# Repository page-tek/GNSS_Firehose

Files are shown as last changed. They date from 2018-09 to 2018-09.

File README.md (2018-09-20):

# GNSS Firehose

Design files for a triband wideband GNSS front-end board.  The board can digitizes three 50 MHz RF channels, emits 2-bit IQ samples to gigabit Ethernet (~800 Mbit/s total payload).

Includes schematics and PCB layout for the hardware design, HDL and software for the FPGA.

The board can by used with Peter Monta's python code (https://github.com/pmonta/GNSS-DSP-tools) or with SDRs like GNSS-SDR (https://gnss-sdr.org/).

See the Github Wiki for more detail on how to use the board.

Open-source licensing.

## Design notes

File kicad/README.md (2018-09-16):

# GNSS Firehose PCB

Created using Kicad 5, there could be issue if the design is opened in Kicad 4.

Changes made from Peter Monta's GNSS Firehose version 2.2 (April 2017) design:
- FPGA changed to Spartan6 XC6SLX16 BGA256 device, the fooprint should be compatable with larger gate devices.
- Power supply topology changes to allow the analog and digital 3V3 sections to be run off different regulators.
- Added the ability to running the frequency generation from external clock source
- Changed obsolite Broadcom MGA-68563 to BGA2800

Layout changes:
- Ground planes cover the outside PCB layers
- Slot in ground plane between TCXO and ethernet components
- more direct traces between the FPGA, Ethernet IC and Ethernet connector

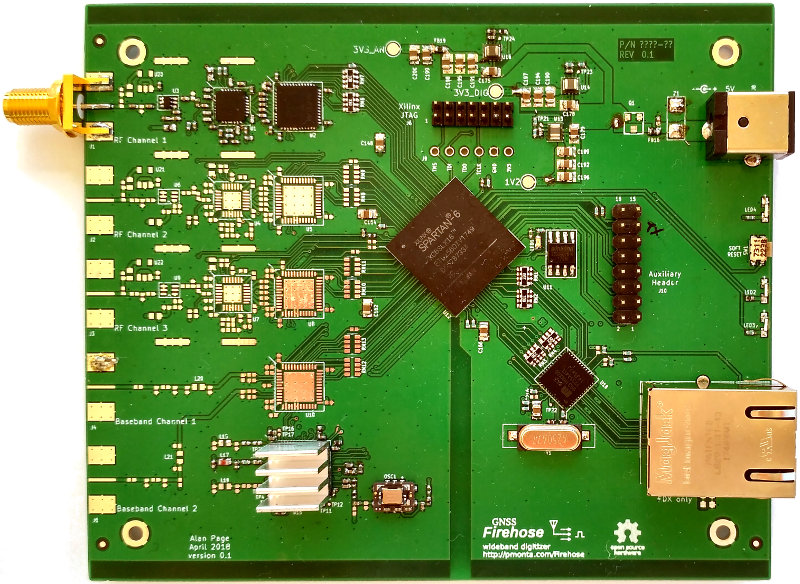
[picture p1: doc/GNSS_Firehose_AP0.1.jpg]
GNSS Firehose Image


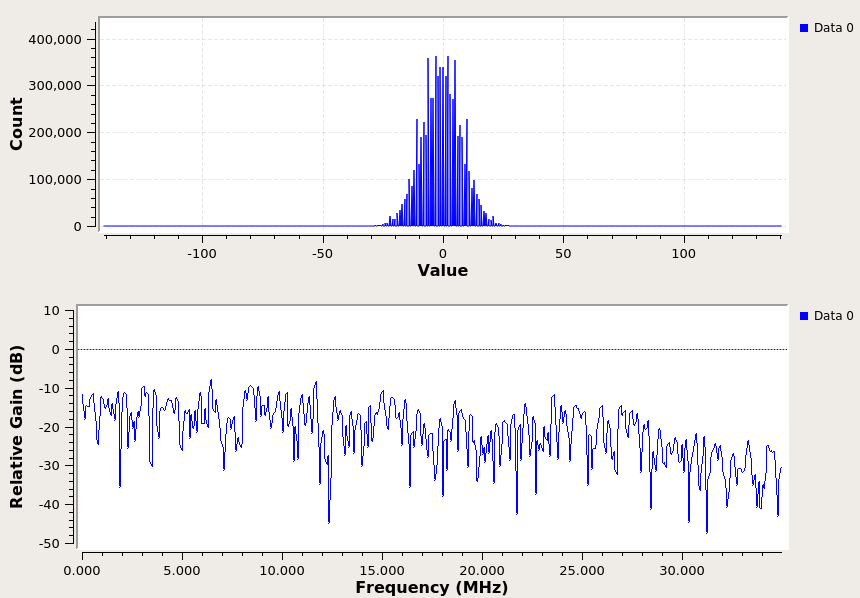
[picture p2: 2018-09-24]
doc/histogram/hist.png

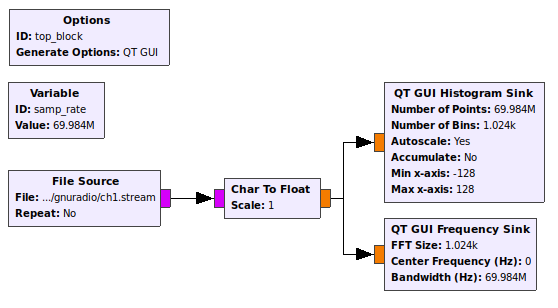
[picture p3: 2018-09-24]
doc/histogram/ch1_stream.png

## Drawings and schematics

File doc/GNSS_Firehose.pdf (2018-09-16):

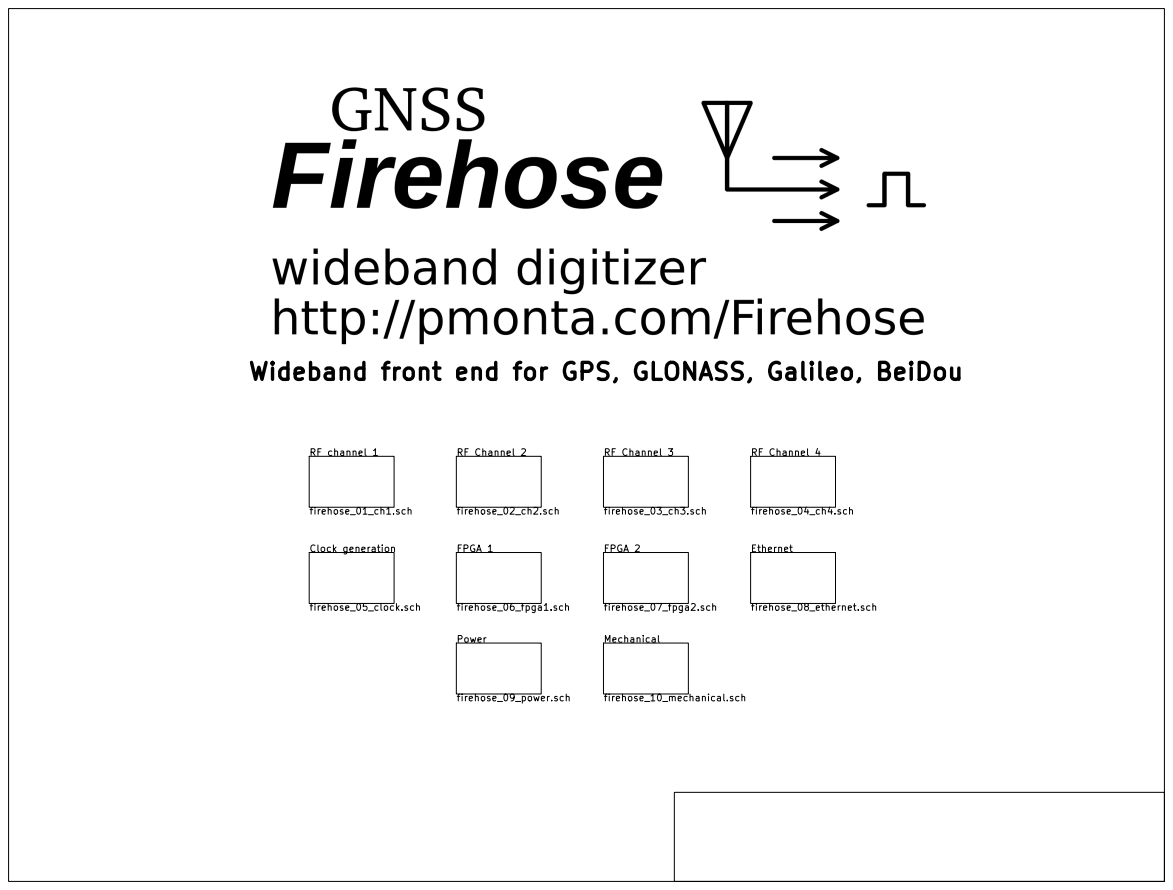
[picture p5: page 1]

Wideband front end for GPS, GLONASS, Galileo, BeiDou

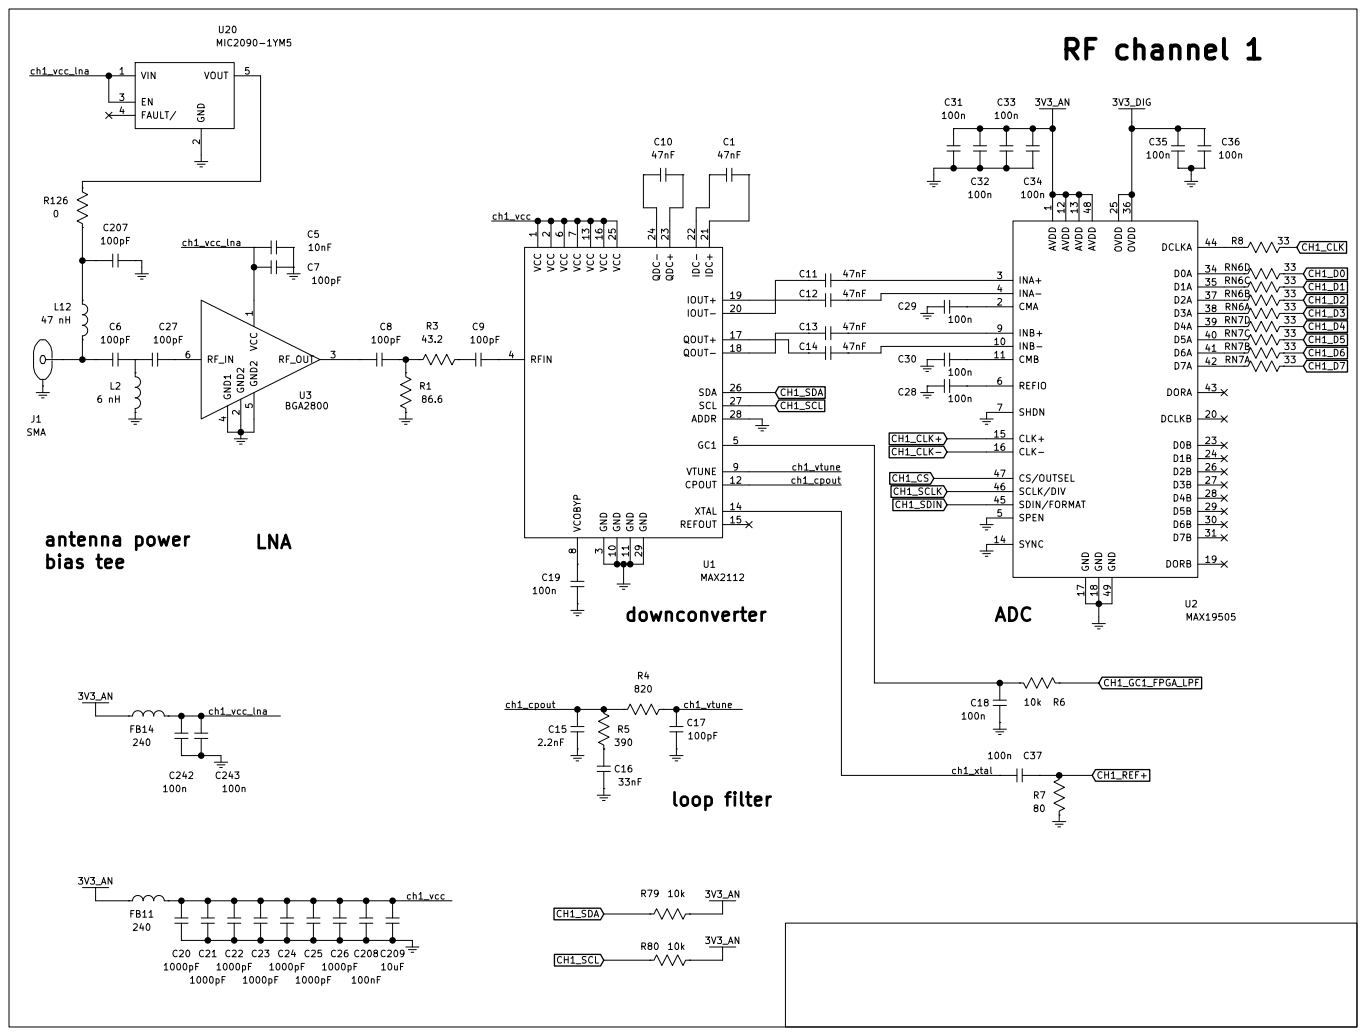
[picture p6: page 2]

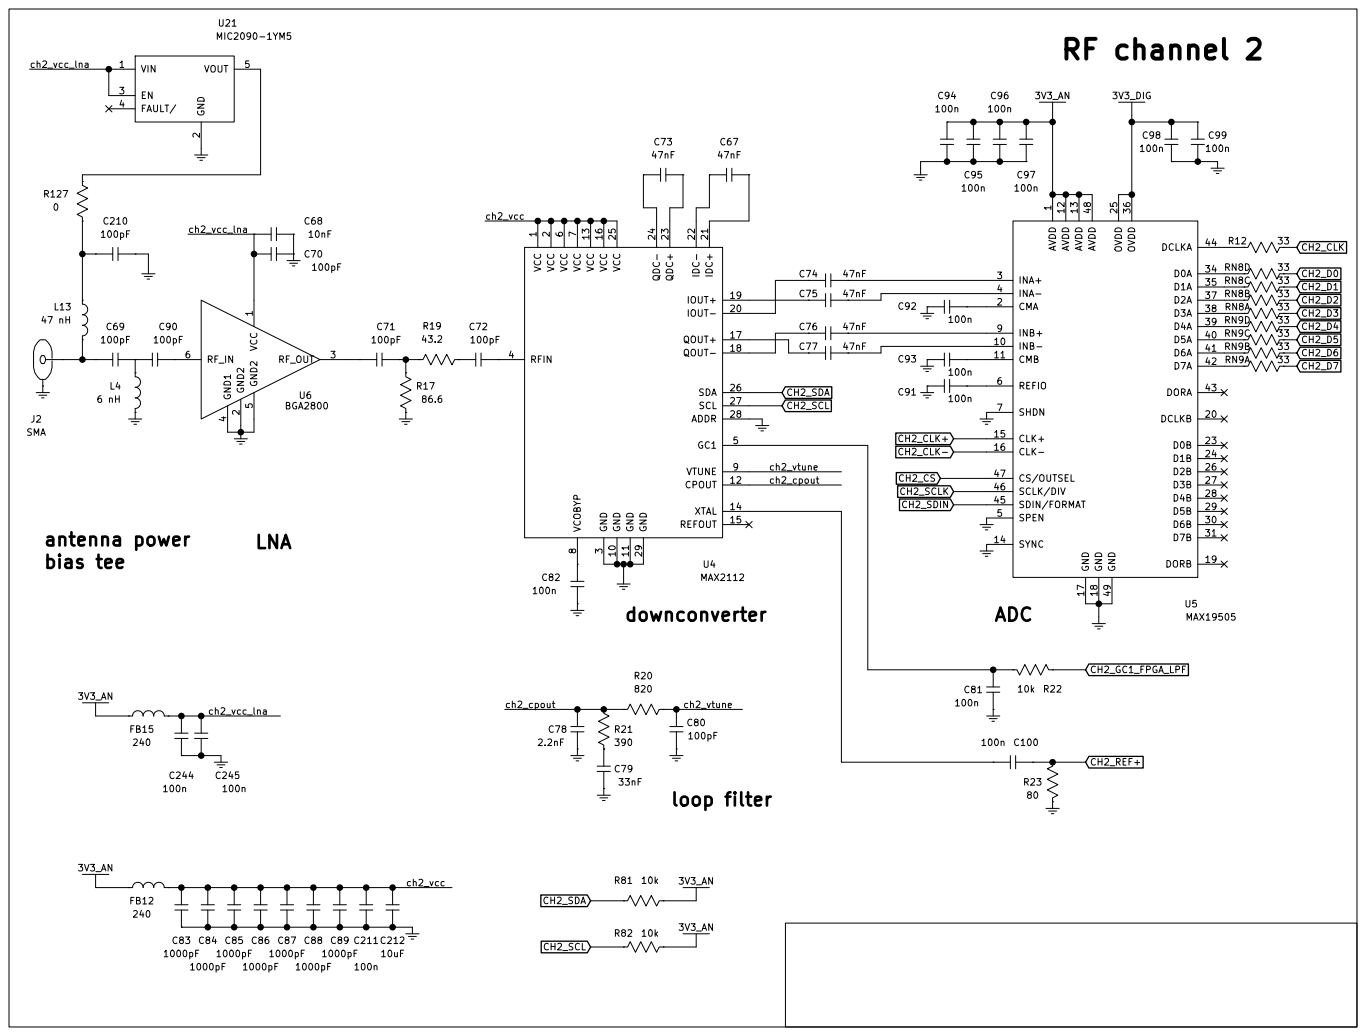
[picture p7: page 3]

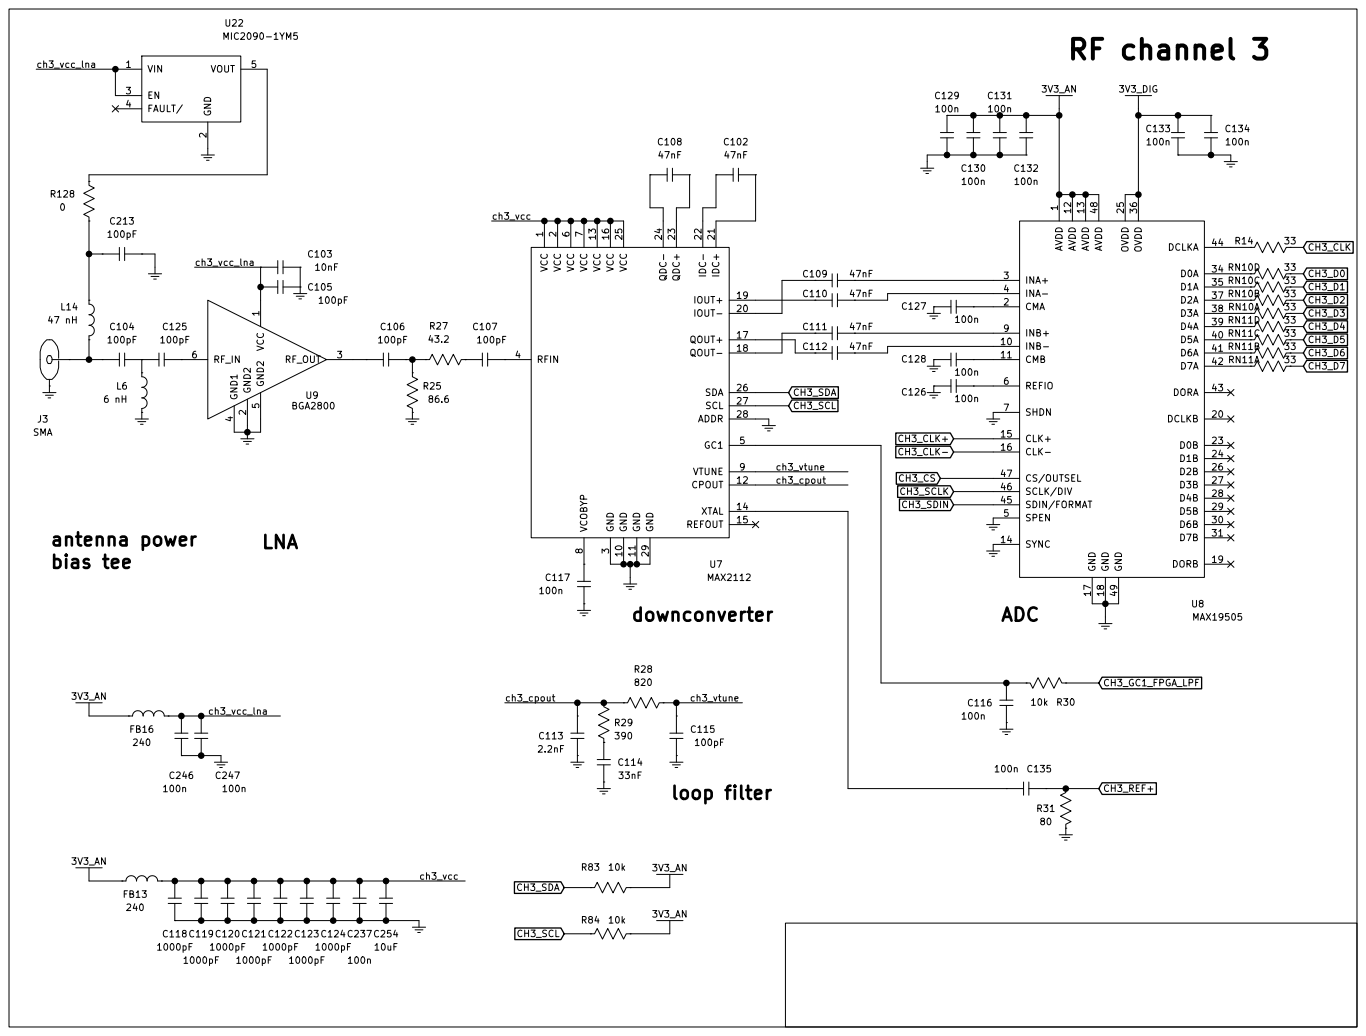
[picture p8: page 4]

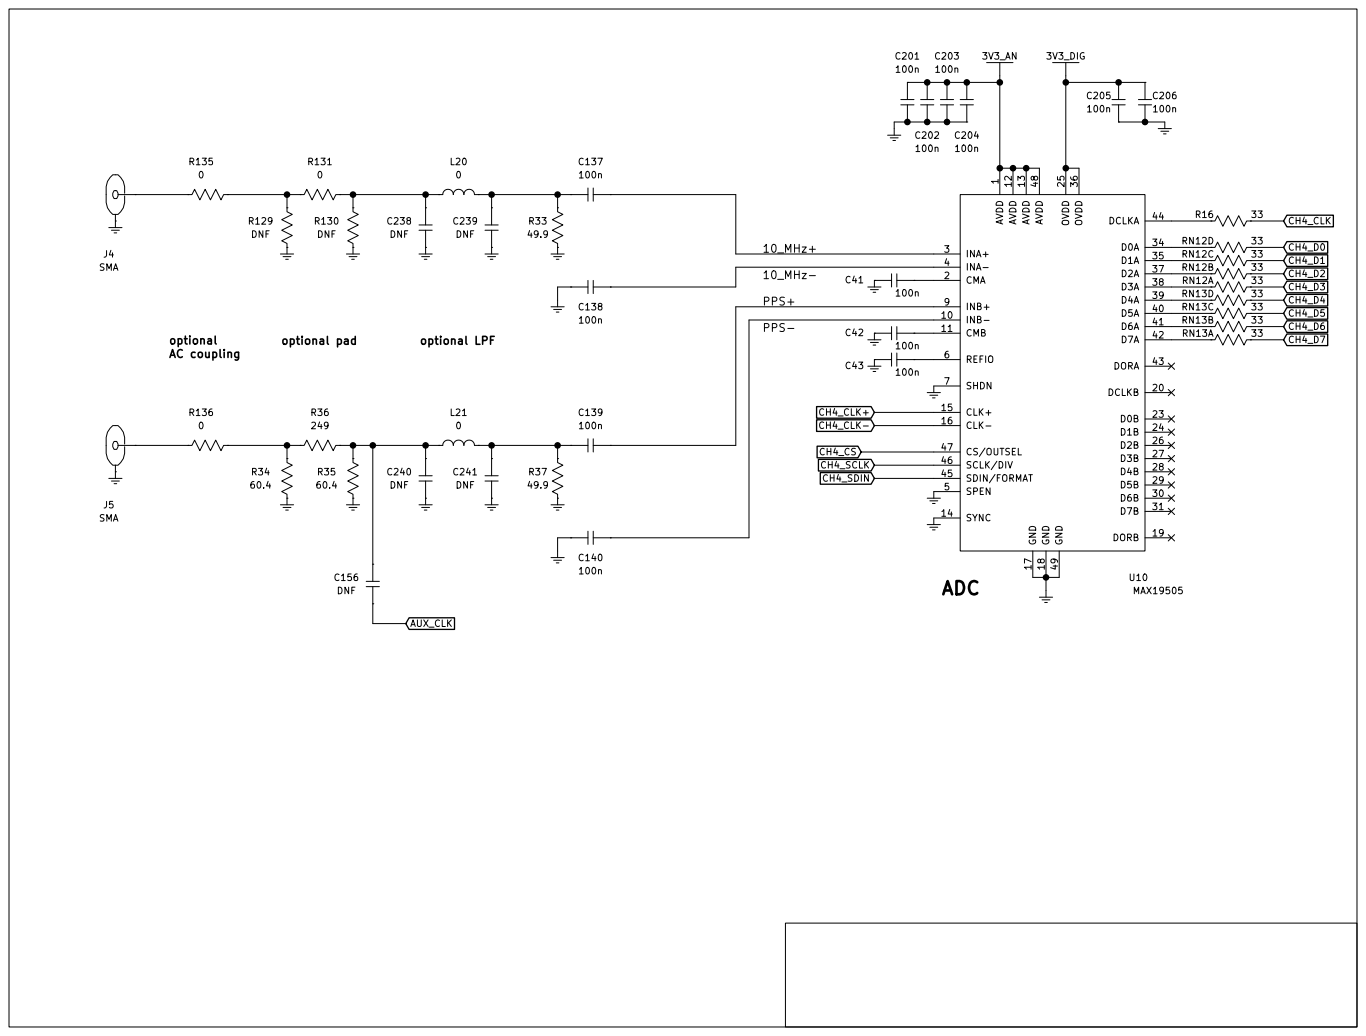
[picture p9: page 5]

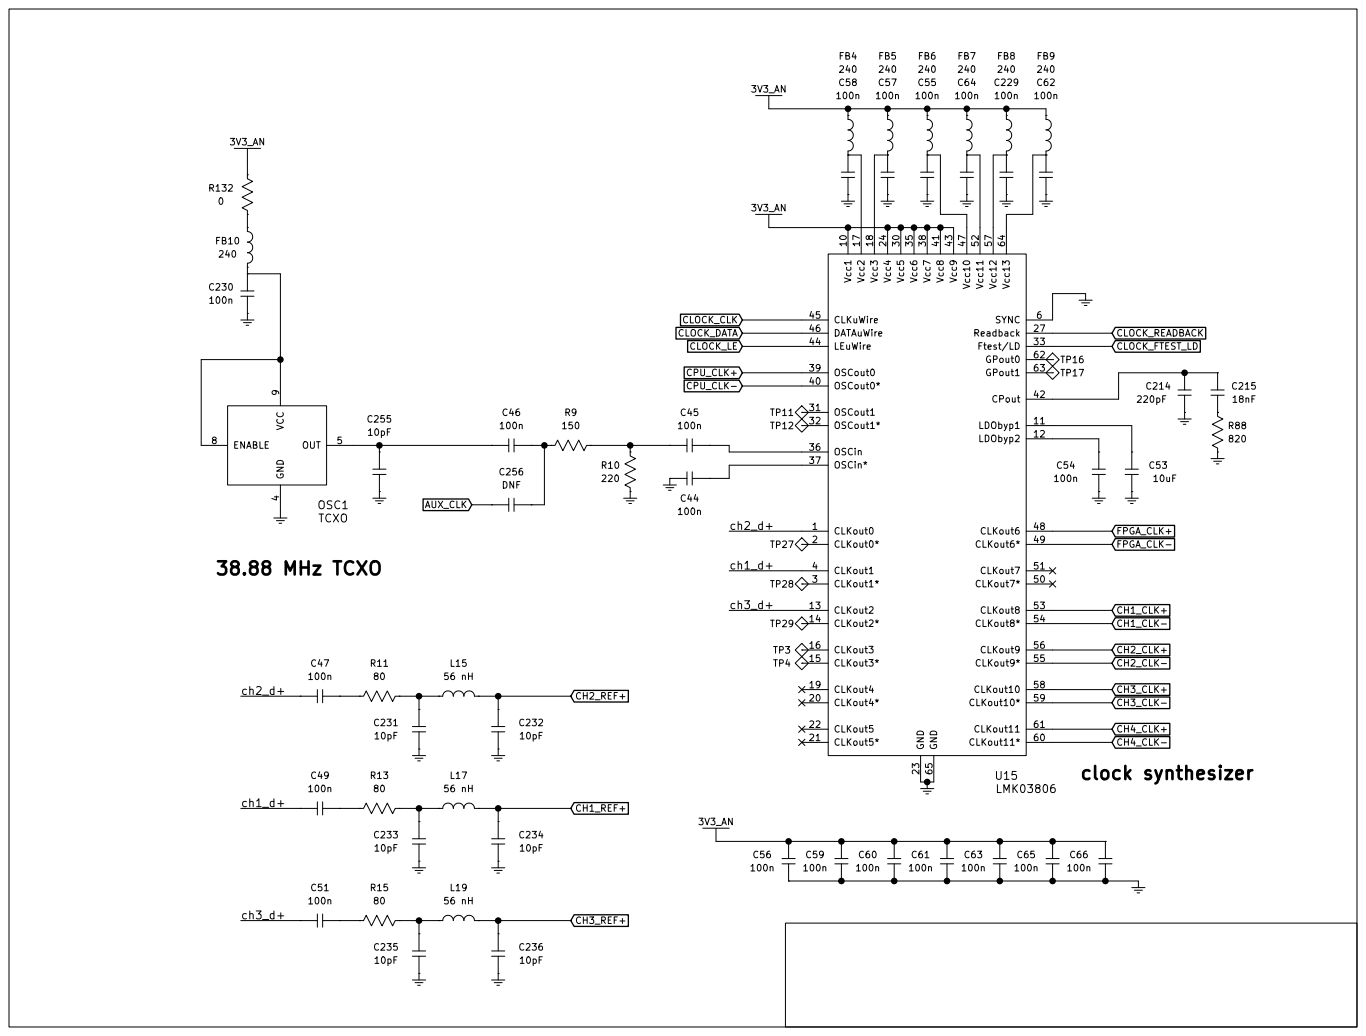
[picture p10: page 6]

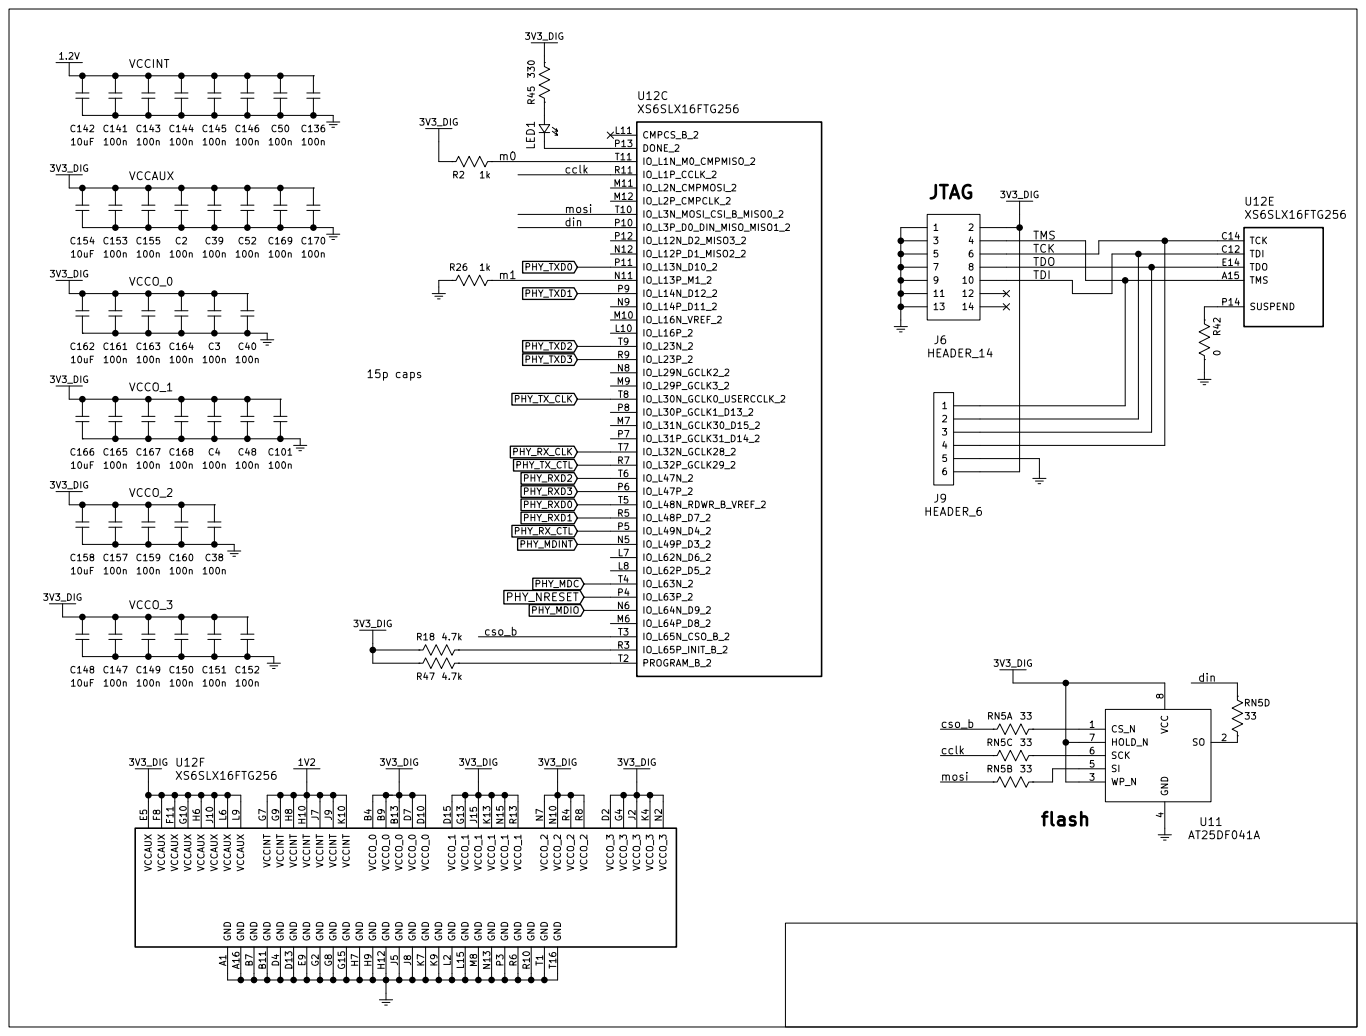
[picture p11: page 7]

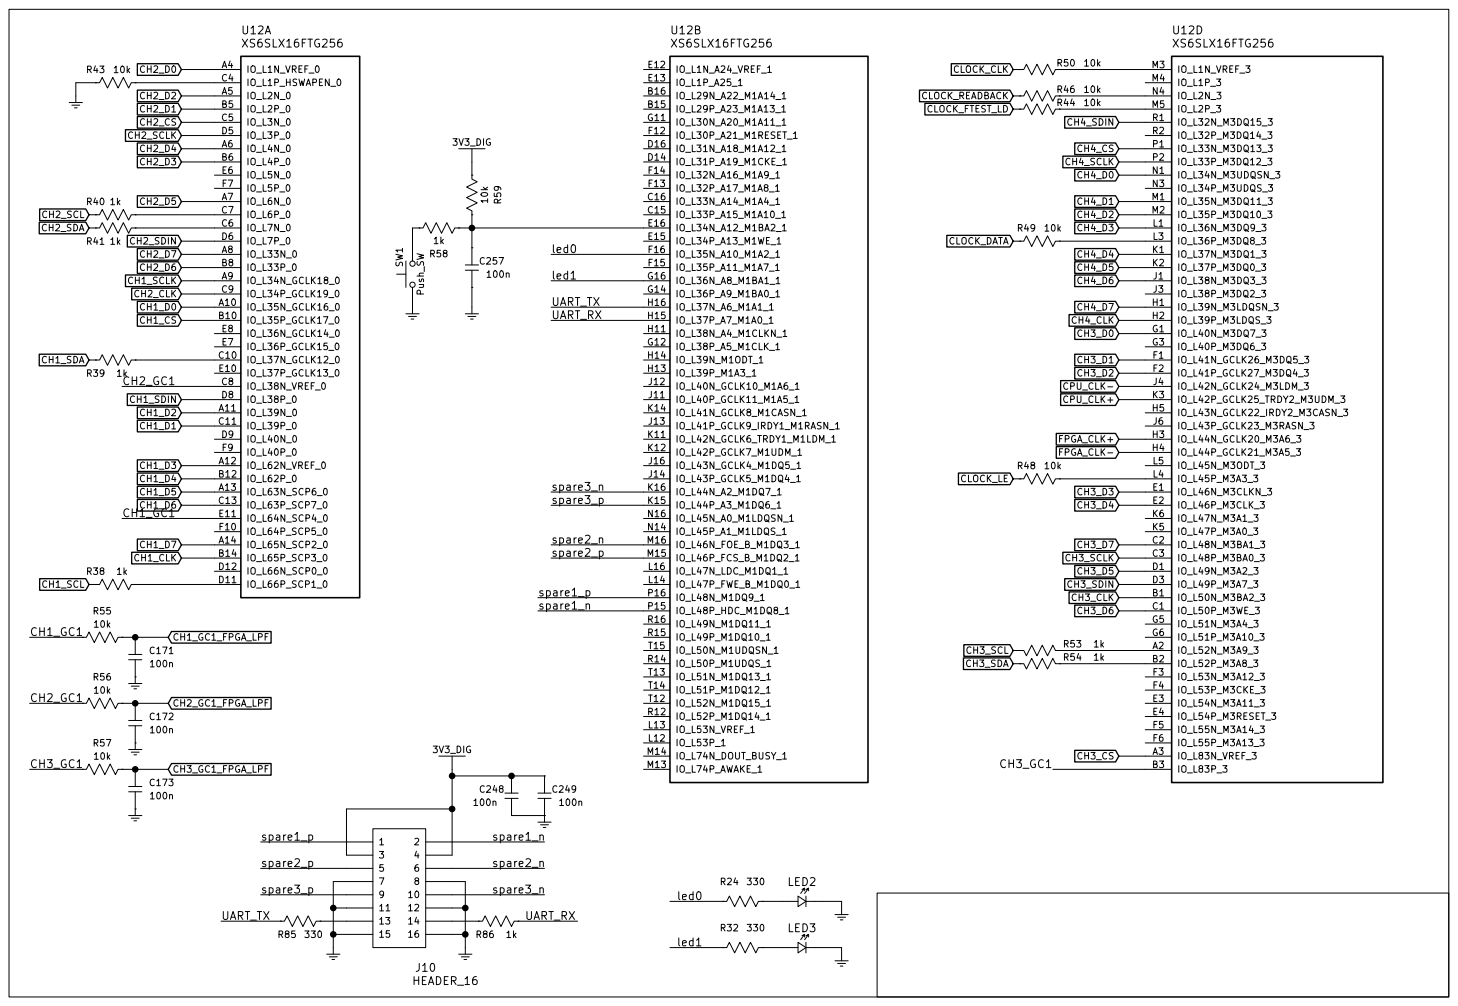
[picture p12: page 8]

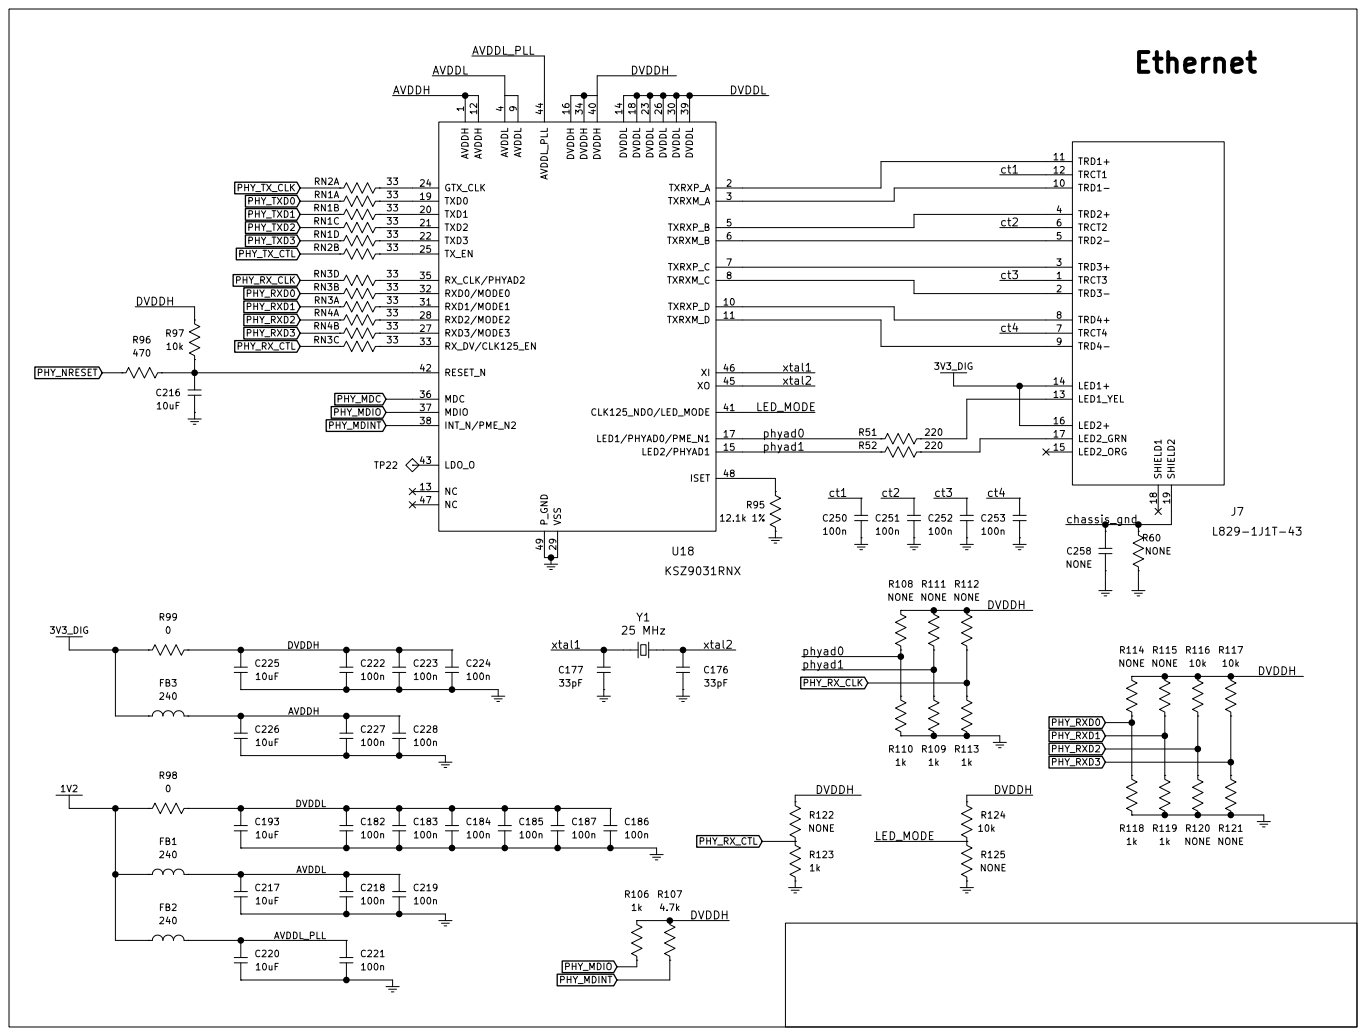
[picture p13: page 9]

9 TXRXP_D 10 TXD1 20 DVDDL 30 DVDDH 40 TXRXM_D 11 TXD2 21 RXD1/MODE1 31 CLK125_NDO/LED_MODE 41 AVDDH 12 TXD3 22 RXD0/MODE0 32 RESET_N 42 NC 13 DVDDL 23 RX_DV/CLK125_EN 33

LED1_YEL 13

LED2+ 16

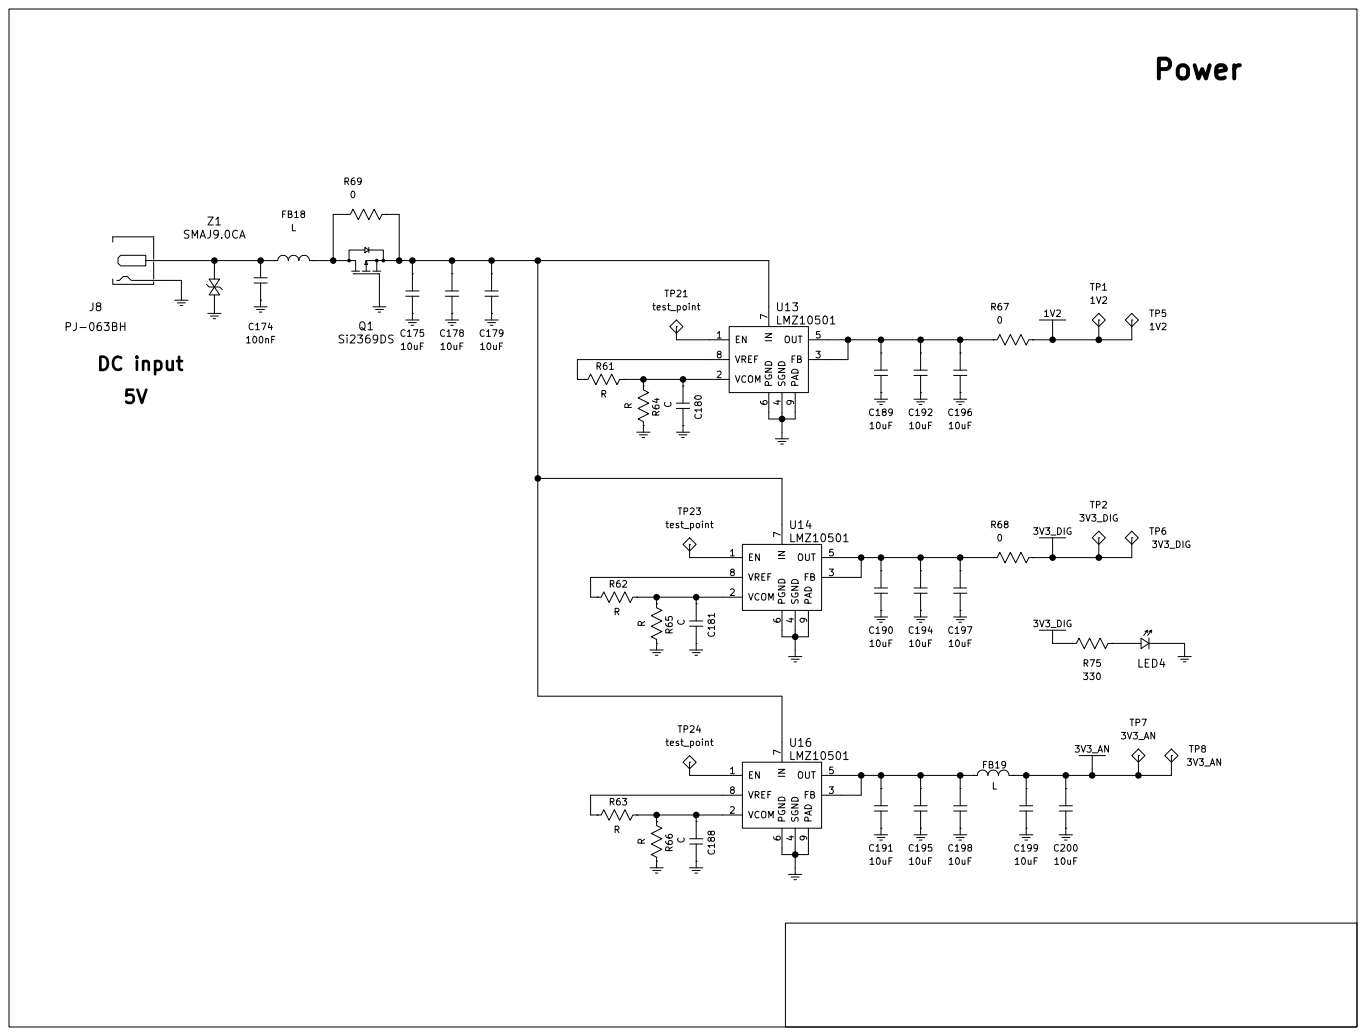
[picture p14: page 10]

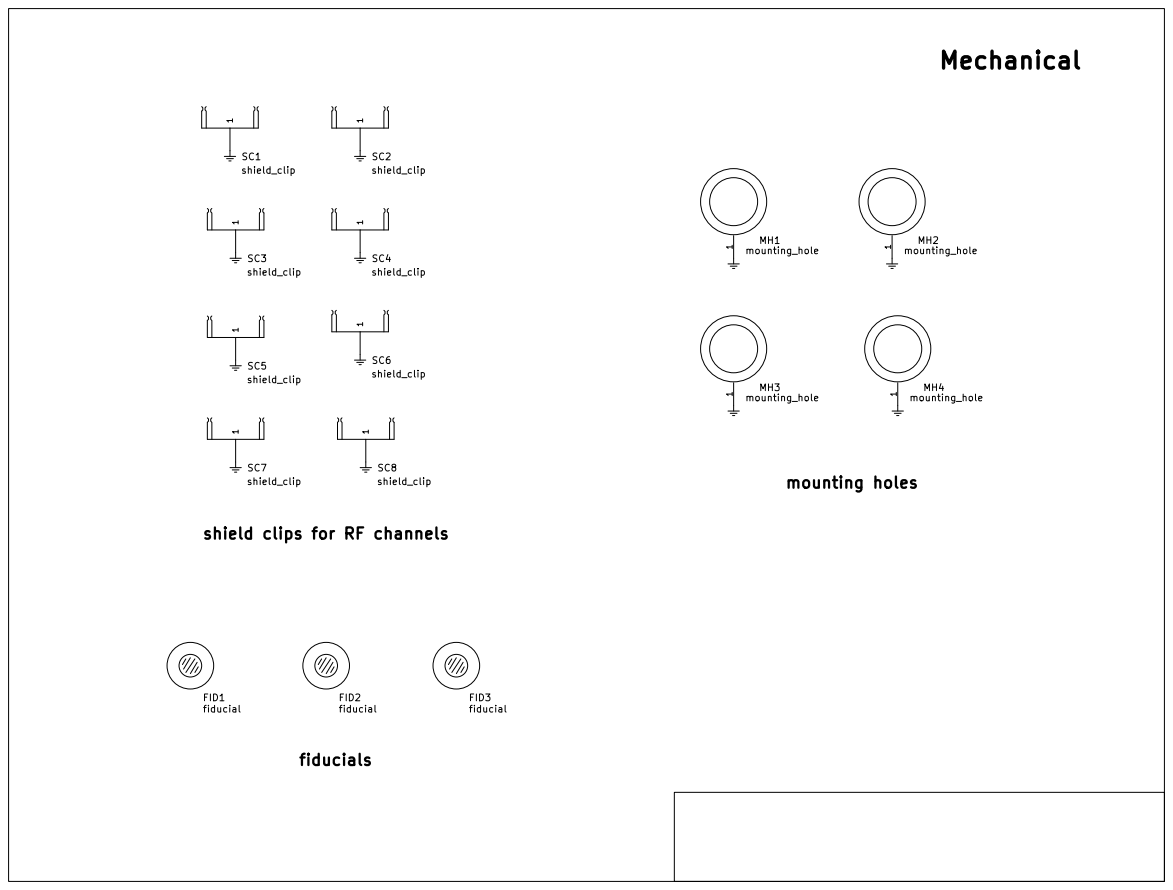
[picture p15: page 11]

shield clips for RF channels

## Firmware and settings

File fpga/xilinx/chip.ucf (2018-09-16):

# FPGA timing and pin-location constraints
#
# GNSS Firehose
# Copyright (c) 2012 Peter Monta <pmonta@gmail.com>

net "clk_adc" tnm_net = "clkADC";
timespec "ts_clkADC" = period "clkADC" 14.5ns;

net "phy_rx_clk" tnm_net = "clkPHY";
timespec "ts_clkPHY" = period "clkPHY" 8ns;

net "clk_tcxo" tnm_net = "clkTCXO";
timespec "ts_clkTCXO" = period "clkTCXO" 25.72ns;

net clk_adc_p loc=H4  | iostandard=lvds_33 | diff_term="true" ;
net clk_adc_n loc=H3  | iostandard=lvds_33 | diff_term="true" ;
net clk_3888_p loc=K3 | iostandard=lvds_33 | diff_term="true" ;
net clk_3888_n loc=J4 | iostandard=lvds_33 | diff_term="true" ;

net ch1_sda loc=C10  | iostandard=lvcmos33 | slew="slow" ;
net ch1_scl loc=D11  | iostandard=lvcmos33 | slew="slow" ;
net ch1_gc1 loc=E11  | iostandard=lvcmos33 | slew="slow" ;
net ch1_cs loc=B10   | iostandard=lvcmos33 | slew="slow" ;
net ch1_sclk loc=A9  | iostandard=lvcmos33 | slew="slow" ;
net ch1_sdin loc=D8  | iostandard=lvcmos33 | slew="slow" ;
net ch1_clk loc=B14  | iostandard=lvcmos33 ;
net ch1_d<0> loc=A10 | iostandard=lvcmos33 ;
net ch1_d<1> loc=C11 | iostandard=lvcmos33 ;
net ch1_d<2> loc=A11 | iostandard=lvcmos33 ;
net ch1_d<3> loc=A12 | iostandard=lvcmos33 ;
net ch1_d<4> loc=B12 | iostandard=lvcmos33 ;
net ch1_d<5> loc=A13 | iostandard=lvcmos33 ;
net ch1_d<6> loc=C13 | iostandard=lvcmos33 ;
net ch1_d<7> loc=A14 | iostandard=lvcmos33 ;

net ch2_sda loc=C6   | iostandard=lvcmos33 | slew="slow" ;
net ch2_scl loc=C7   | iostandard=lvcmos33 | slew="slow" ;
net ch2_gc1 loc=C8   | iostandard=lvcmos33 | slew="slow" ;
net ch2_cs loc=C5    | iostandard=lvcmos33 | slew="slow" ;
net ch2_sclk loc=D5  | iostandard=lvcmos33 | slew="slow" ;
net ch2_sdin loc=D6  | iostandard=lvcmos33 | slew="slow" ;
net ch2_clk loc=C9   | iostandard=lvcmos33 ;
net ch2_d<0> loc=A4  | iostandard=lvcmos33 ;
net ch2_d<1> loc=B5  | iostandard=lvcmos33 ;
net ch2_d<2> loc=A5  | iostandard=lvcmos33 ;
net ch2_d<3> loc=B6  | iostandard=lvcmos33 ;
net ch2_d<4> loc=A6  | iostandard=lvcmos33 ;
net ch2_d<5> loc=A7  | iostandard=lvcmos33 ;
net ch2_d<6> loc=B8  | iostandard=lvcmos33 ;
net ch2_d<7> loc=A8  | iostandard=lvcmos33 ;

net ch3_sda loc=B2   | iostandard=lvcmos33 | slew="slow" ;
net ch3_scl loc=A2   | iostandard=lvcmos33 | slew="slow" ;
net ch3_gc1 loc=B3   | iostandard=lvcmos33 | slew="slow" ;
net ch3_cs loc=A3    | iostandard=lvcmos33 | slew="slow" ;
net ch3_sclk loc=C3  | iostandard=lvcmos33 | slew="slow" ;
net ch3_sdin loc=D3  | iostandard=lvcmos33 | slew="slow" ;
net ch3_clk loc=B1   | iostandard=lvcmos33 ;
net ch3_d<0> loc=G1  | iostandard=lvcmos33 ;
net ch3_d<1> loc=F1  | iostandard=lvcmos33 ;
net ch3_d<2> loc=F2  | iostandard=lvcmos33 ;
net ch3_d<3> loc=E1  | iostandard=lvcmos33 ;
net ch3_d<4> loc=E2  | iostandard=lvcmos33 ;
net ch3_d<5> loc=D1  | iostandard=lvcmos33 ;
net ch3_d<6> loc=C1  | iostandard=lvcmos33 ;
net ch3_d<7> loc=C2  | iostandard=lvcmos33 ;

net ch4_cs loc=G3    | iostandard=lvcmos33 | slew="slow" ;
net ch4_sclk loc=P1  | iostandard=lvcmos33 | slew="slow" ;
net ch4_sdin loc=P2  | iostandard=lvcmos33 | slew="slow" ;
net ch4_clk loc=H2   | iostandard=lvcmos33 ;
net ch4_d<0> loc=N1  | iostandard=lvcmos33 ;
net ch4_d<1> loc=M1  | iostandard=lvcmos33 ;
net ch4_d<2> loc=M2  | iostandard=lvcmos33 ;
net ch4_d<3> loc=L1  | iostandard=lvcmos33 ;
net ch4_d<4> loc=K1  | iostandard=lvcmos33 ;
net ch4_d<5> loc=K2  | iostandard=lvcmos33 ;
net ch4_d<6> loc=J1  | iostandard=lvcmos33 ;
net ch4_d<7> loc=H1  | iostandard=lvcmos33 ;

net phy_tx_clk loc=T8     | iostandard=lvcmos33 ;
net phy_tx_data<0> loc=P11 | iostandard=lvcmos33 ;
net phy_tx_data<1> loc=P9 | iostandard=lvcmos33 ;
net phy_tx_data<2> loc=T9 | iostandard=lvcmos33 ;
net phy_tx_data<3> loc=R9 | iostandard=lvcmos33 ;
net phy_tx_ctl loc=R7     | iostandard=lvcmos33 ;

net phy_rx_clk loc=T7     | iostandard=lvcmos33 ;
net phy_rx_data<0> loc=T5 | iostandard=lvcmos33 ;
net phy_rx_data<1> loc=R5 | iostandard=lvcmos33 ;
net phy_rx_data<2> loc=T6 | iostandard=lvcmos33 ;
net phy_rx_data<3> loc=P6 | iostandard=lvcmos33 ;
net phy_rx_ctl loc=P5     | iostandard=lvcmos33 ;

net phy_mdc loc=T4        | iostandard=lvcmos33 | slew="slow" ;
net phy_mdio loc=N6       | iostandard=lvcmos33 | slew="slow" ;
net phy_mdint loc=N5      | iostandard=lvcmos33 ;
net phy_nreset loc=P4     | iostandard=lvcmos33 | slew="slow" ;

net clock_clk loc=M3      | iostandard=lvcmos33 | slew="slow" ;
net clock_data loc=L3     | iostandard=lvcmos33 | slew="slow" ;
net clock_le loc=L4       | iostandard=lvcmos33 | slew="slow" ;
net clock_readback loc=N4 | iostandard=lvcmos33 ;
net clock_ftest_ld loc=M5 | iostandard=lvcmos33 ;

net uart_rx loc=H15       | iostandard=lvcmos33 ;
net uart_tx loc=H16       | iostandard=lvcmos33 | slew="slow" ;

net led0 loc=F16          | iostandard=lvcmos33 | slew="slow" ;
net led1 loc=G16          | iostandard=lvcmos33 | slew="slow" ;

net spi_cclk  loc=R11 | iostandard=lvcmos33 | slew="slow" ;
net spi_din   loc=P10 | iostandard=lvcmos33 ;
net spi_mosi  loc=T10 | iostandard=lvcmos33 | slew="slow" ;
net spi_cso_b loc=T3  | iostandard=lvcmos33 | slew="slow" ;

net spare1_p loc=P16  | iostandard=lvcmos33 ;
net spare1_n loc=P15  | iostandard=lvcmos33 ;
net spare2_p loc=M15  | iostandard=lvcmos33 ;
net spare2_n loc=M16  | iostandard=lvcmos33 ;
net spare3_p loc=K15  | iostandard=lvcmos33 ;
net spare3_n loc=K16  | iostandard=lvcmos33 ;

net "*streamer_enable*" tig;
net "*packet_count*" tig;
net "*activity_clk_adc*" tig;
net "*activity_phy_tx_clk*" tig;
net "*mac_addr*" tig;
net "*eth_rx_ready*" tig;
net "*eth_rx_read*" tig;
net "*eth_tx_ready*" tig;

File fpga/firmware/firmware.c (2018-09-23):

// GNSS Firehose firmware
//
// Copyright 2017 Peter Monta
//

#define N_CHANNEL 3
#define N_ADC     4

unsigned int jiffies;           // system time
int link_up;                    // Ethernet link status
int phy_poll_enable;            // poll the Ethernet PHY SMI bus
int agc_enable;                 // gain control: automatic or manual
int gain[N_CHANNEL];            // channel gains (10-bit PWM)

#include "delay.c"
#include "io.c"
#include "clock.c"
#include "adc.c"
#include "max2112.c"
#include "agc.c"
#include "ethernet.c"
#include "flash.c"
#include "cmd.c"

void eth_service()
{ if (!eth_rx_ready())
    return;
  process_eth_packet(); }

void uart_service()
{ if (!uart_rx_ready())
    return;
  process_char(uart_rx_data()); }

void hw_init()
{ clock_init();
  port_write(PORT_DCM_RST,1);
  delay_10ms();
  port_write(PORT_DCM_RST,0);
  delay_10ms();
  //adc_init(1);
  //adc_init(2);
  //adc_init(3);
  //adc_init(4);
  max2112_init(1,45,0x4a000);  // RF channel 1, N=45 (L1), F=0x4a000  1584.754875 MHz
  //max2112_init(2,35,0x16000);  // RF channel 2, N=35 (L2), F=0x16000  1227.727125 MHz
  //max2112_init(3,34,0x0e000);  // RF channel 3, N=34 (L5), F=0x0e000  1191.641625 MHz
  set_agc(1,240);              // initial AGC value: 240
  set_agc(2,240);
  set_agc(3,240);
  phy_poll_enable = 1;         // enable PHY polling by default
  agc_enable = 1;              // enable AGC by default
  spi_read_config(); }         // read and apply configuration and calibration parameters from flash

void poll()
{ unsigned int j;
  j = get_jiffies();
  if (j==jiffies)          // has jiffies counter changed?
    return;
  jiffies = j;             // do once per jiffy (once per approx. 30 ms):
  if (agc_enable)
    agc_service();         // service the AGC loops
  if (phy_poll_enable)
    phy_service(); }       // poll Ethernet PHY for link status

//
// main loop
//

int main()
{ hw_init();            // initialize hardware

  for (;;) {
    uart_service();     // service any UART commands
    eth_service();      // service any Ethernet commands
    poll(); }           // low-rate polling of various background services

  return 0; }

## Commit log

2018-09-16 Updated PCB
    [GNSS_Firehose.kicad_pcb, GNSS_Firehose.sch, GNSS_Firehose_BOM.csv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]
2018-09-16 Update xilinx files to xc6slx16-2ftg256. Remove old CAM files
    [GNSS_Firehose-B.Cu.gbr, GNSS_Firehose-B.Mask.gbr, GNSS_Firehose-B.Paste.gbr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]
2018-09-16 Updated project README, added signal flow documentation.
2018-09-20 PWM changed to sigma-delta
    Changed destination MAC from broadcast to fixed.
    [packet_streamer.v]
2018-09-23 Updated for new board, just 1 channel initalized.
